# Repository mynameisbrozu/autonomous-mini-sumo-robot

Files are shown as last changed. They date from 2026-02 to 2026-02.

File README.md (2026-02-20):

## Autonomous mini sumo robot based on black pill STM32f411 microcontroller
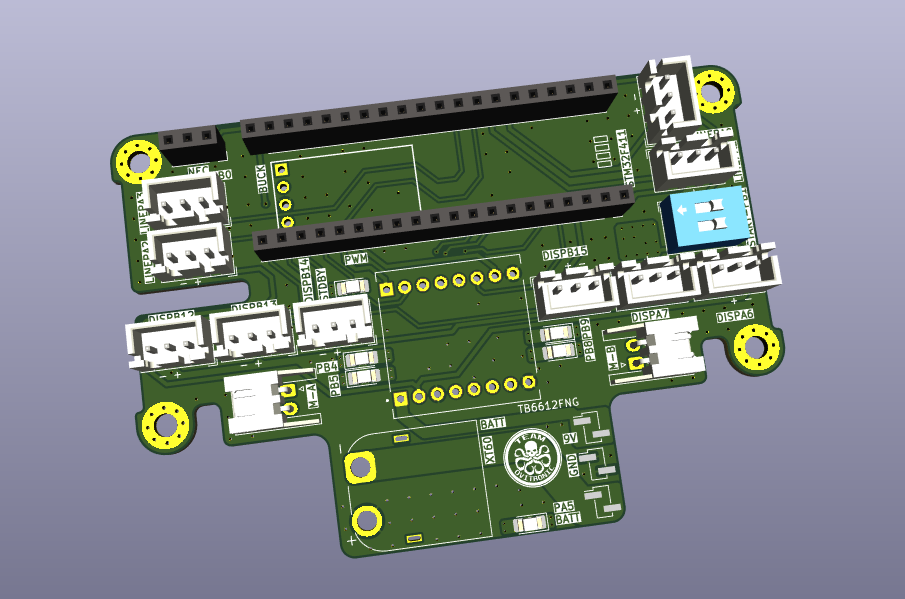
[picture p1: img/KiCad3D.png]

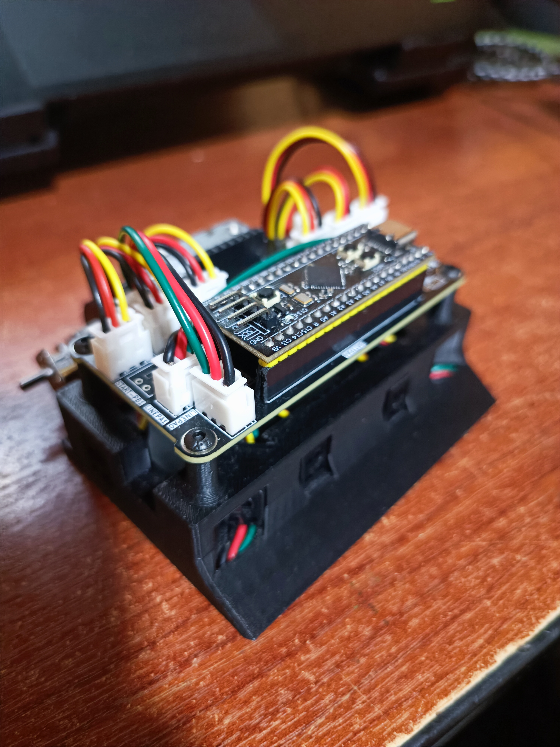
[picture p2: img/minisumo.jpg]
 
## PCB in KiCad 
| Schematic | Routing |
|---|---|
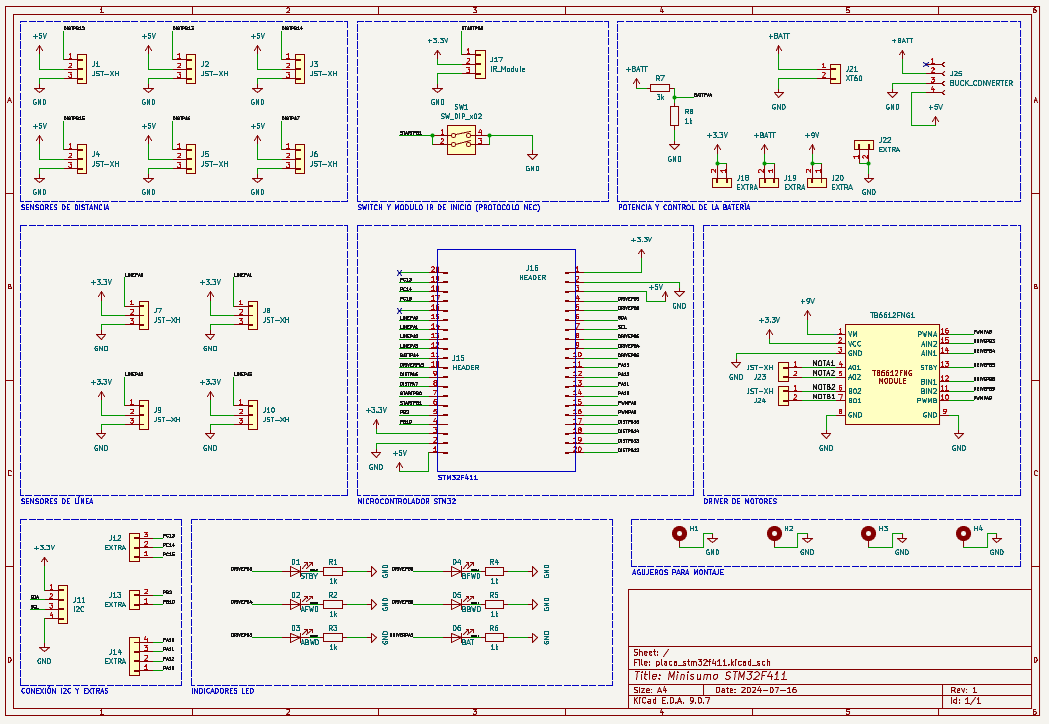
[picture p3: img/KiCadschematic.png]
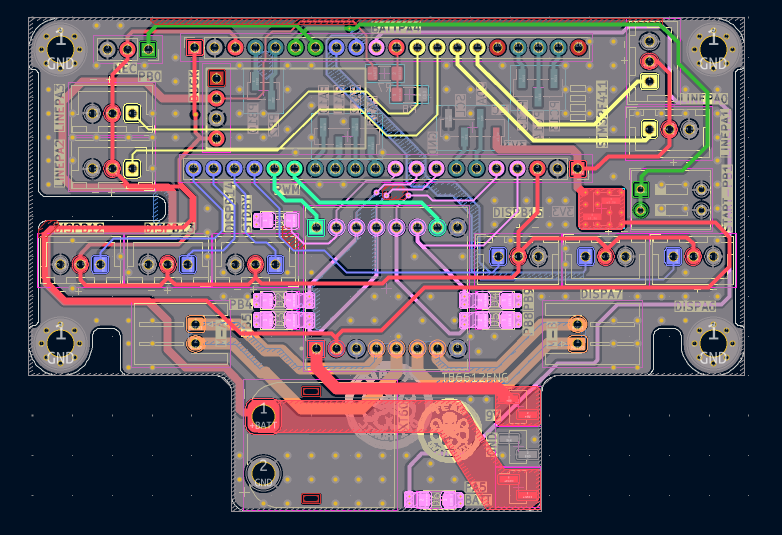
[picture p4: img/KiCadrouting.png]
|  |  |
## Pin selection - STM32F411
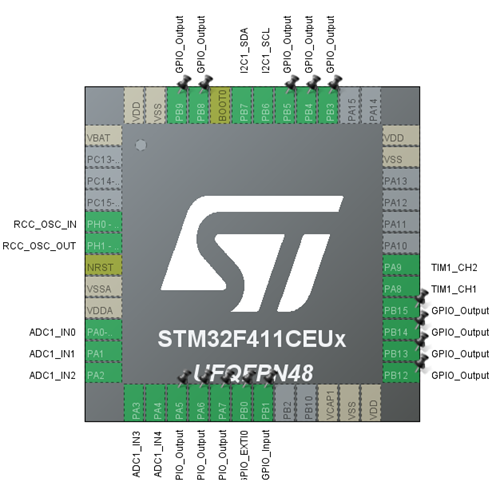
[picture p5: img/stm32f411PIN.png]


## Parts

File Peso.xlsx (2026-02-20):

 | Cantidad | Peso (gr) | TOTAL (gr)
Tornillos | 8 | 1.4 | 11.2
STM32 | 1 | 7.1 | 7.1
Placa | 1 | 32.1 | 32.1
Sensor de distancia | 6 | 3.1 | 18.6
Sensor de linea | 2 | 0.9 | 1.8
Batería | 1 | 97.7 | 97.7
Módulo IR | 1 | 2.1 | 2.1
Motores | 2 | 22 | 44
Ruedas | 2 | 23 | 46
TOTAL |  |  | 260.6 | gramos
Partes impresas | 239.4 |  |  | gramos

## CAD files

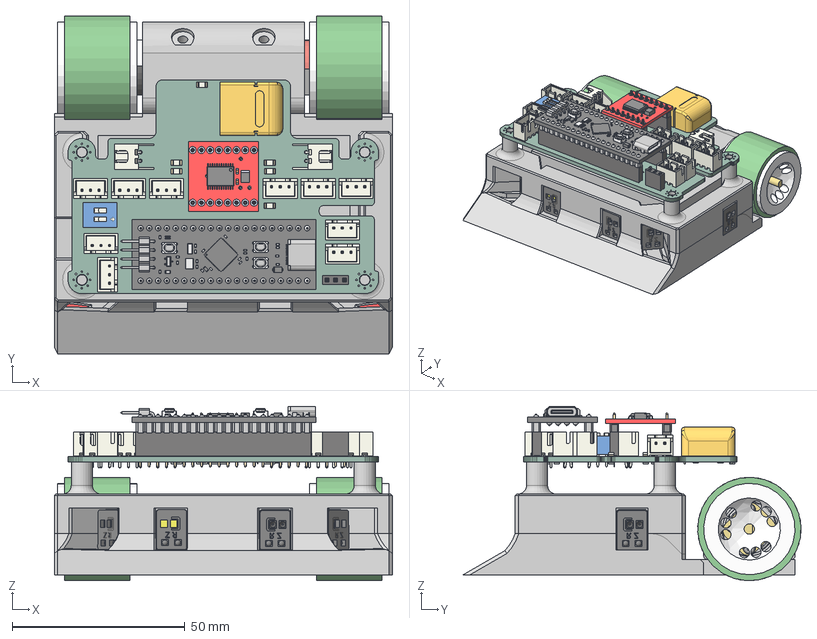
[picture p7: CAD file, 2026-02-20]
CAD/SumoPromedio.step
98.1 x 98.0 x 50.5 mm
16mm Dc Motor x 2
Wheel sumoZade x 2
rubber sumozade x 2
Chasis
qtr-1a-reflectance-sensor
qtr-1a-reflectance-sensor v1(Mirror)
RZ60S - Base x 3
RZ60S - Plastico Amarelo x 6
RZ60S - Base(Mirror)
RZ60S - Base(Mirror) (1)
RZ60S - Base(Mirror) (2)
BATERIA2S
LED_1206_3216Metric_6 x 6
JST_B3B_XH_A x 10
JST_S2B_XH_A_1 x 2
ROB-14450_1
PinSocket_1x08_P254mm_Vertical x 2
PinSocket_1x20_P254mm_Vertical x 2
XT60PW-M_1
SW_DIP_SPSTx02_Slide_978x726mm_W762mm_P254mm
PinSocket_1x03_P254mm_Vertical
R_1206_3216Metric_8 x 8
_autosave-placa_stm32f411 PCB
Board_001
STM32F4 Chip_001
Surface Mount Transistor_001
0603 Resistor_001
0603 Capacitor_001
0402 Capacitor_001
0402 Resistor_001
0402 Resistor_002
0402 Resistor_003
0402 Resistor_004
0402 Resistor_005
0402 Resistor_006
0402 Resistor_007
0402 Resistor_008
0402 Capacitor_002
0402 Capacitor_003
0402 Capacitor_004
0402 Capacitor_005
0402 Capacitor_006
0402 Capacitor_007
0402 Capacitor_008
0402 Capacitor_009
0402 Capacitor_010
0402 Capacitor_011
0402 Capacitor_012
0402 Capacitor_013
Diode 2_001
SM LED_001
1x20 Male Header_001
1x20 Male Header_002
Tac Switch_001
Tac Switch_002
Tac Switch_003
USB-C Connector_001
1x4 Right Angle Male Header_001
Crystal 1_001
Crystal 2_001

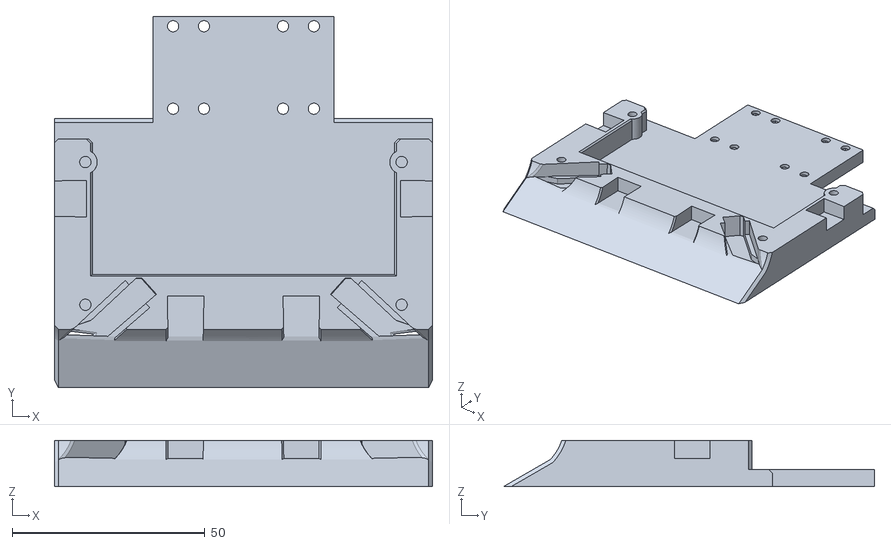
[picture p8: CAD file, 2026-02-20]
Chasis/STLs/Base principal.stl
98.0 x 96.2 x 12.0

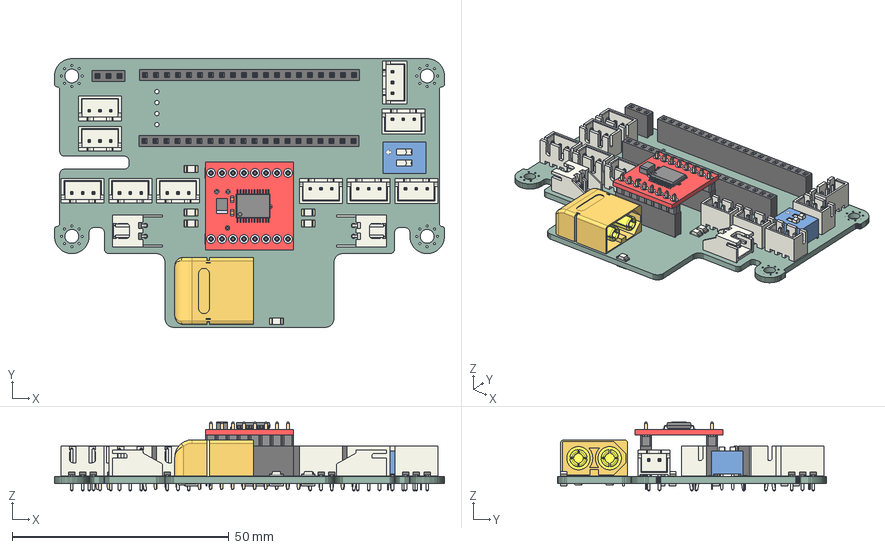
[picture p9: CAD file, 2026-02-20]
placa_stm32f411/placa_stm32f411.step
90.0 x 62.0 x 15.9 mm
LED_1206_3216Metric x 6
JST_B3B_XH_A x 10
JST_S2B_XH_A_1 x 2
ROB-14450
PinSocket_1x08_P254mm_Vertical x 2
PinSocket_1x20_P254mm_Vertical x 2
XT60PW-M
SW_DIP_SPSTx02_Slide_978x726mm_W762mm_P254mm
PinSocket_1x03_P254mm_Vertical
R_1206_3216Metric x 8
_autosave-placa_stm32f411 PCB

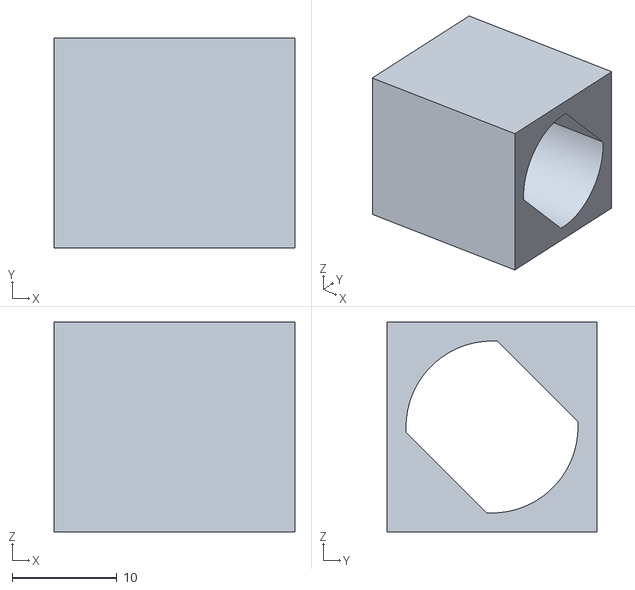
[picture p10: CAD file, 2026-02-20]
Pruebas_tolerancias/pruebaLONG_enganche_motor_t0p2.stl
23.0 x 20.0 x 20.0

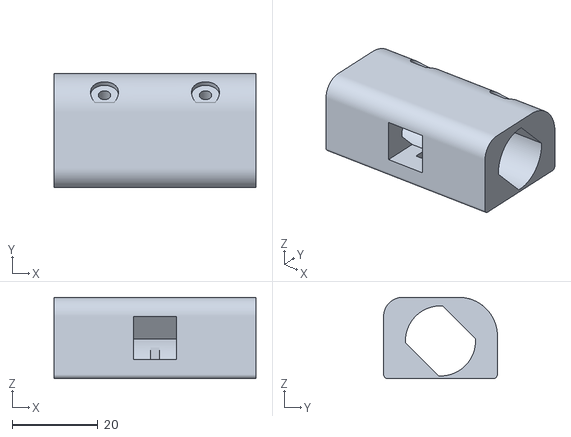
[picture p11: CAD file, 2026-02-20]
Chasis/Enganche de motores_rev1.stl
47.0 x 26.5 x 18.9

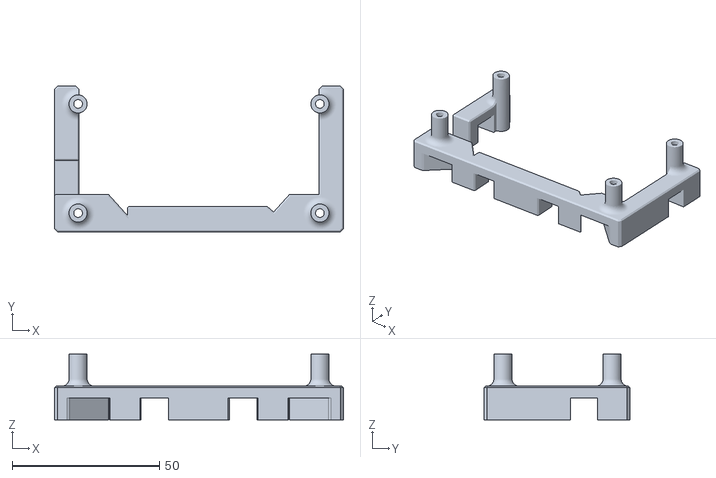
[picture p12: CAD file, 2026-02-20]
Chasis/STLs/Cubierta superior.stl
98.0 x 49.4 x 22.3

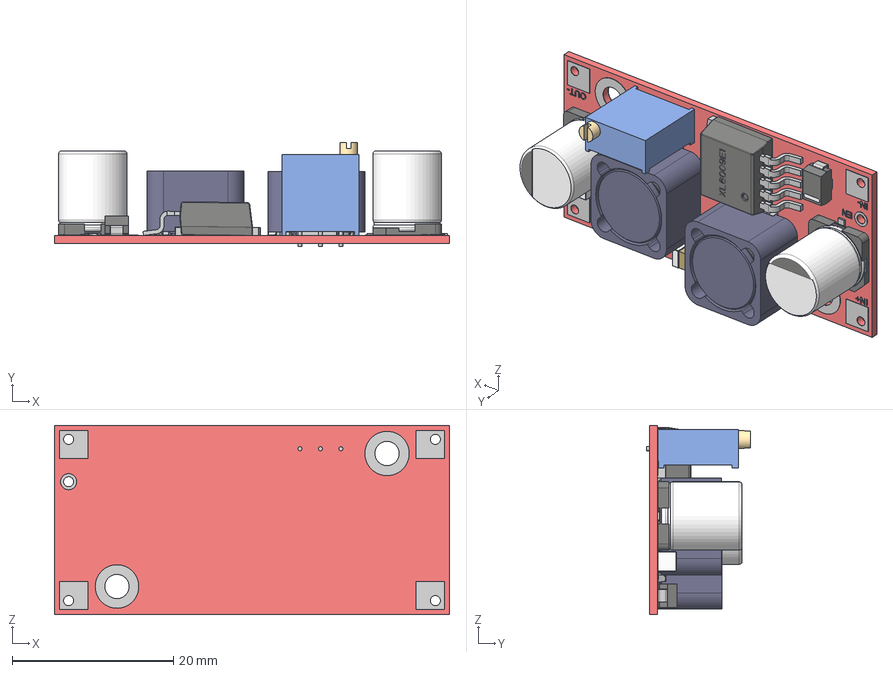
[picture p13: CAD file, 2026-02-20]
placa_stm32f411/xl6009_DCDC_BoostBuck.step
49.0 x 13.0 x 23.5 mm
KERN_ x 2
KERN___1_ x 2
KERN___2_ x 2
SCHALE_ x 2
PIN_ x 2
PIN___1_ x 2
3296W_V3
CAPACITOR1 x 2
Pads
Screen

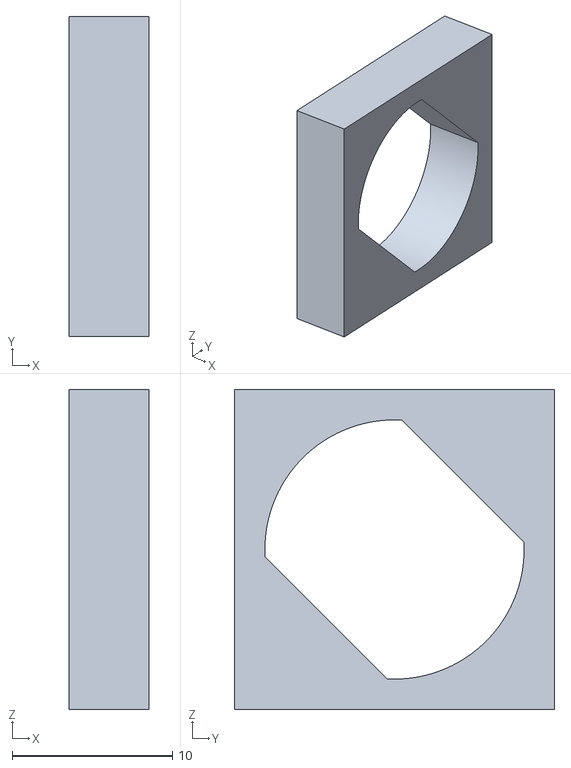
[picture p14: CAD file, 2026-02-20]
Pruebas_tolerancias/prueba_enganche_motor_t0p1.stl
5.00 x 20.0 x 20.0

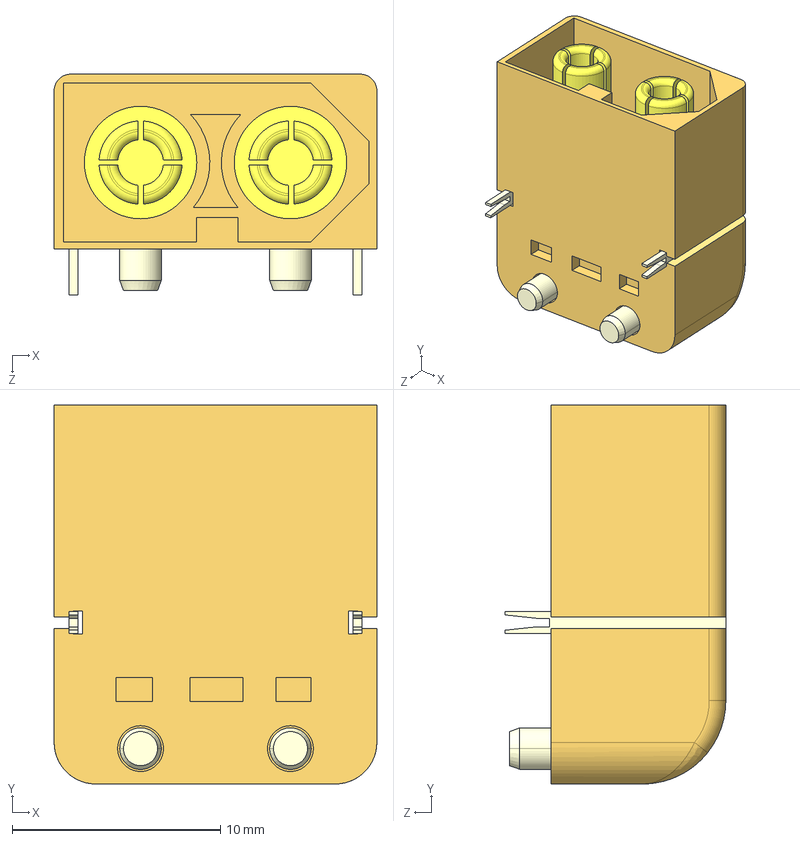
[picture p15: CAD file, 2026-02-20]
placa_stm32f411/XT60PW-M.STEP
15.5 x 18.2 x 10.6 mm

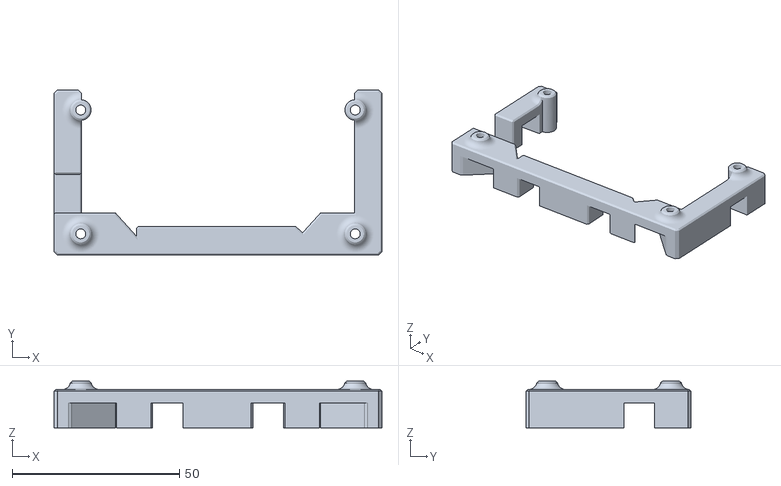
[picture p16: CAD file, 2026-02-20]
Chasis/Cubierta superior_rev2.stl
98.0 x 49.4 x 13.9

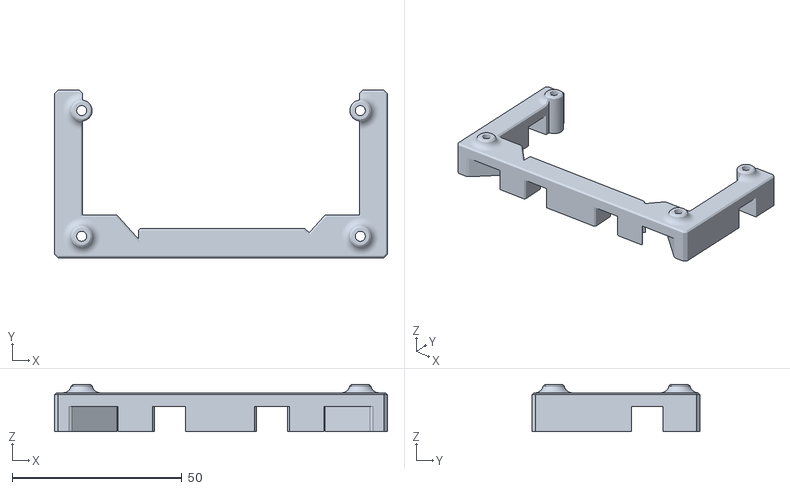
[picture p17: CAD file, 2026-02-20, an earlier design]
Chasis/Cubierta superior_rev1.stl
98.0 x 49.4 x 13.9

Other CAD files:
Chasis/Base principal_rev2.stl
Chasis/STLs/Enganche de motores.stl
Pruebas_tolerancias/prueba_enganche_motor_t0p3.stl
Pruebas_tolerancias/pruebaLONG_enganche_motor_t0p15.stl
Pruebas_tolerancias/prueba_enganche_motor_t0p2.stl
Pruebas_tolerancias/prueba_enganche_motor.stl
Chasis/Base principal_rev1.stl
placa_stm32f411/xl6009_DCDC_BoostBuck.f3d

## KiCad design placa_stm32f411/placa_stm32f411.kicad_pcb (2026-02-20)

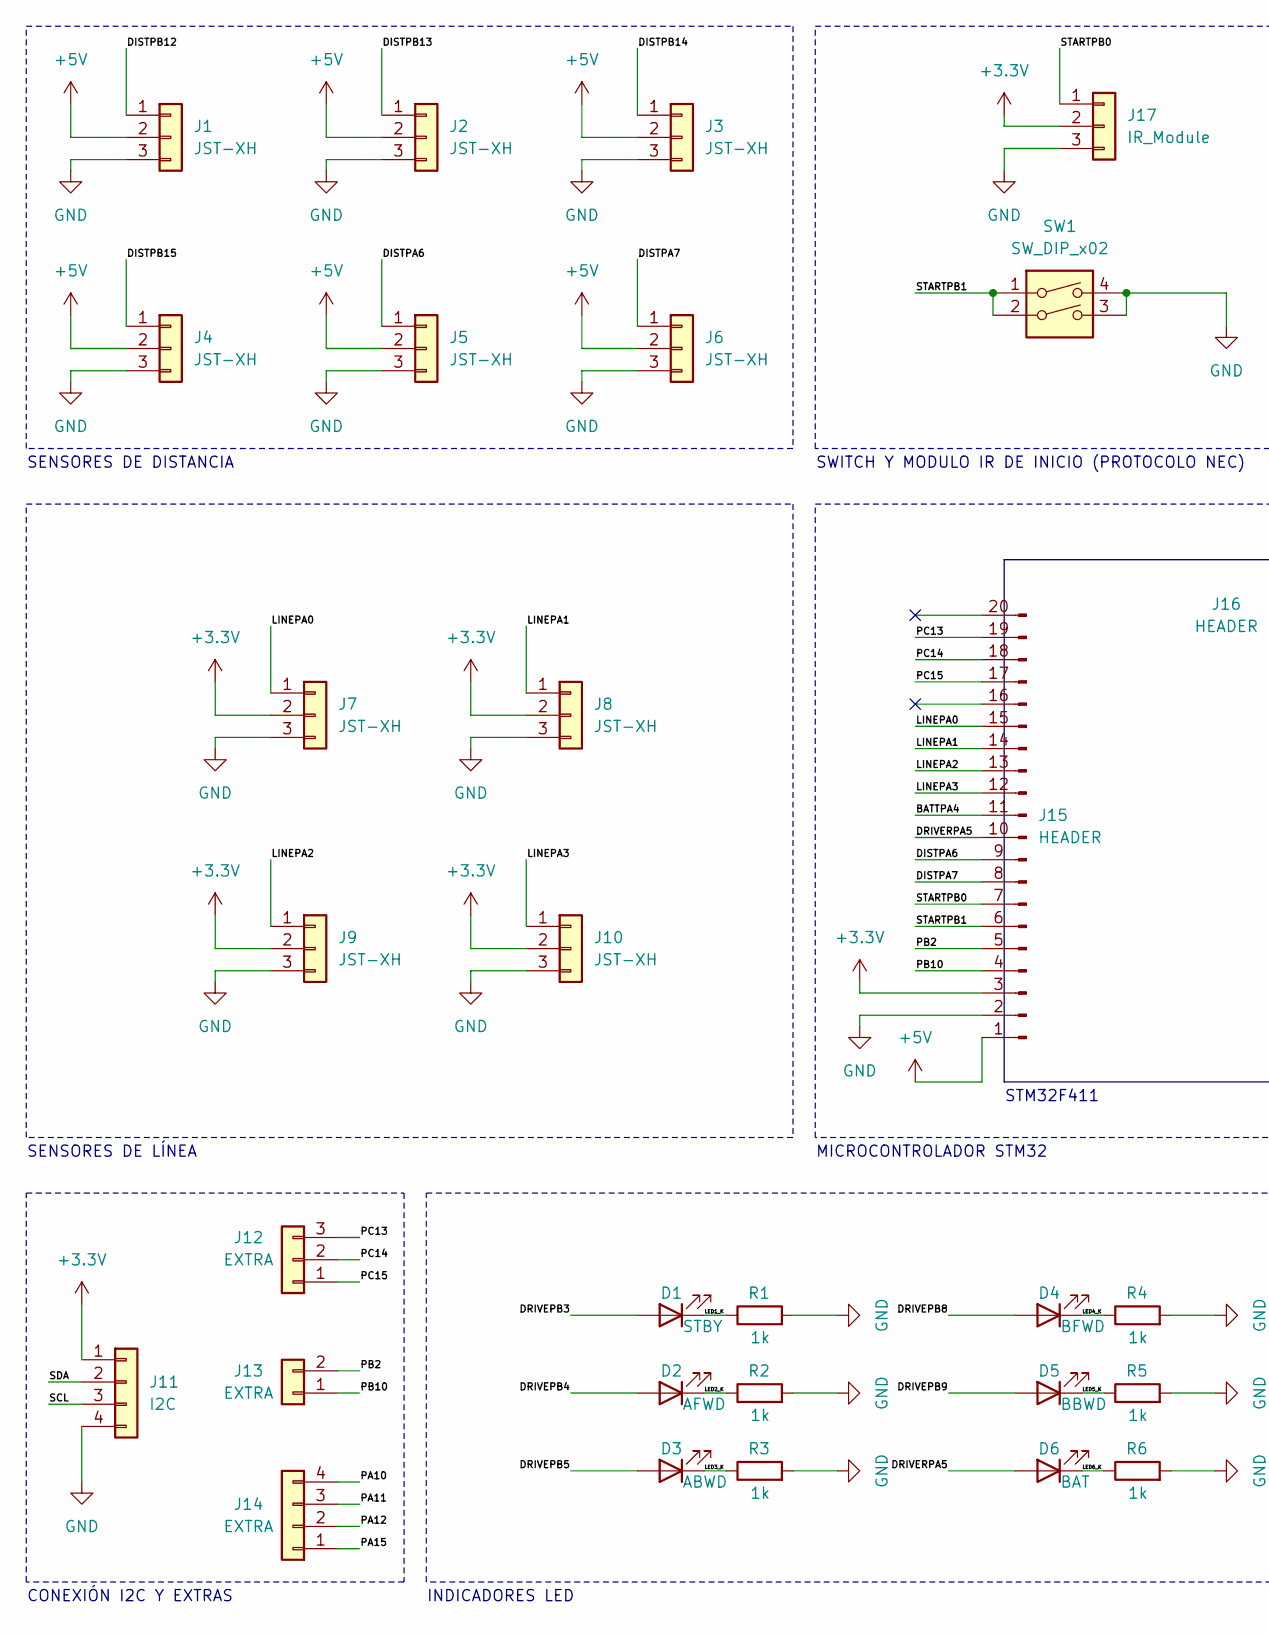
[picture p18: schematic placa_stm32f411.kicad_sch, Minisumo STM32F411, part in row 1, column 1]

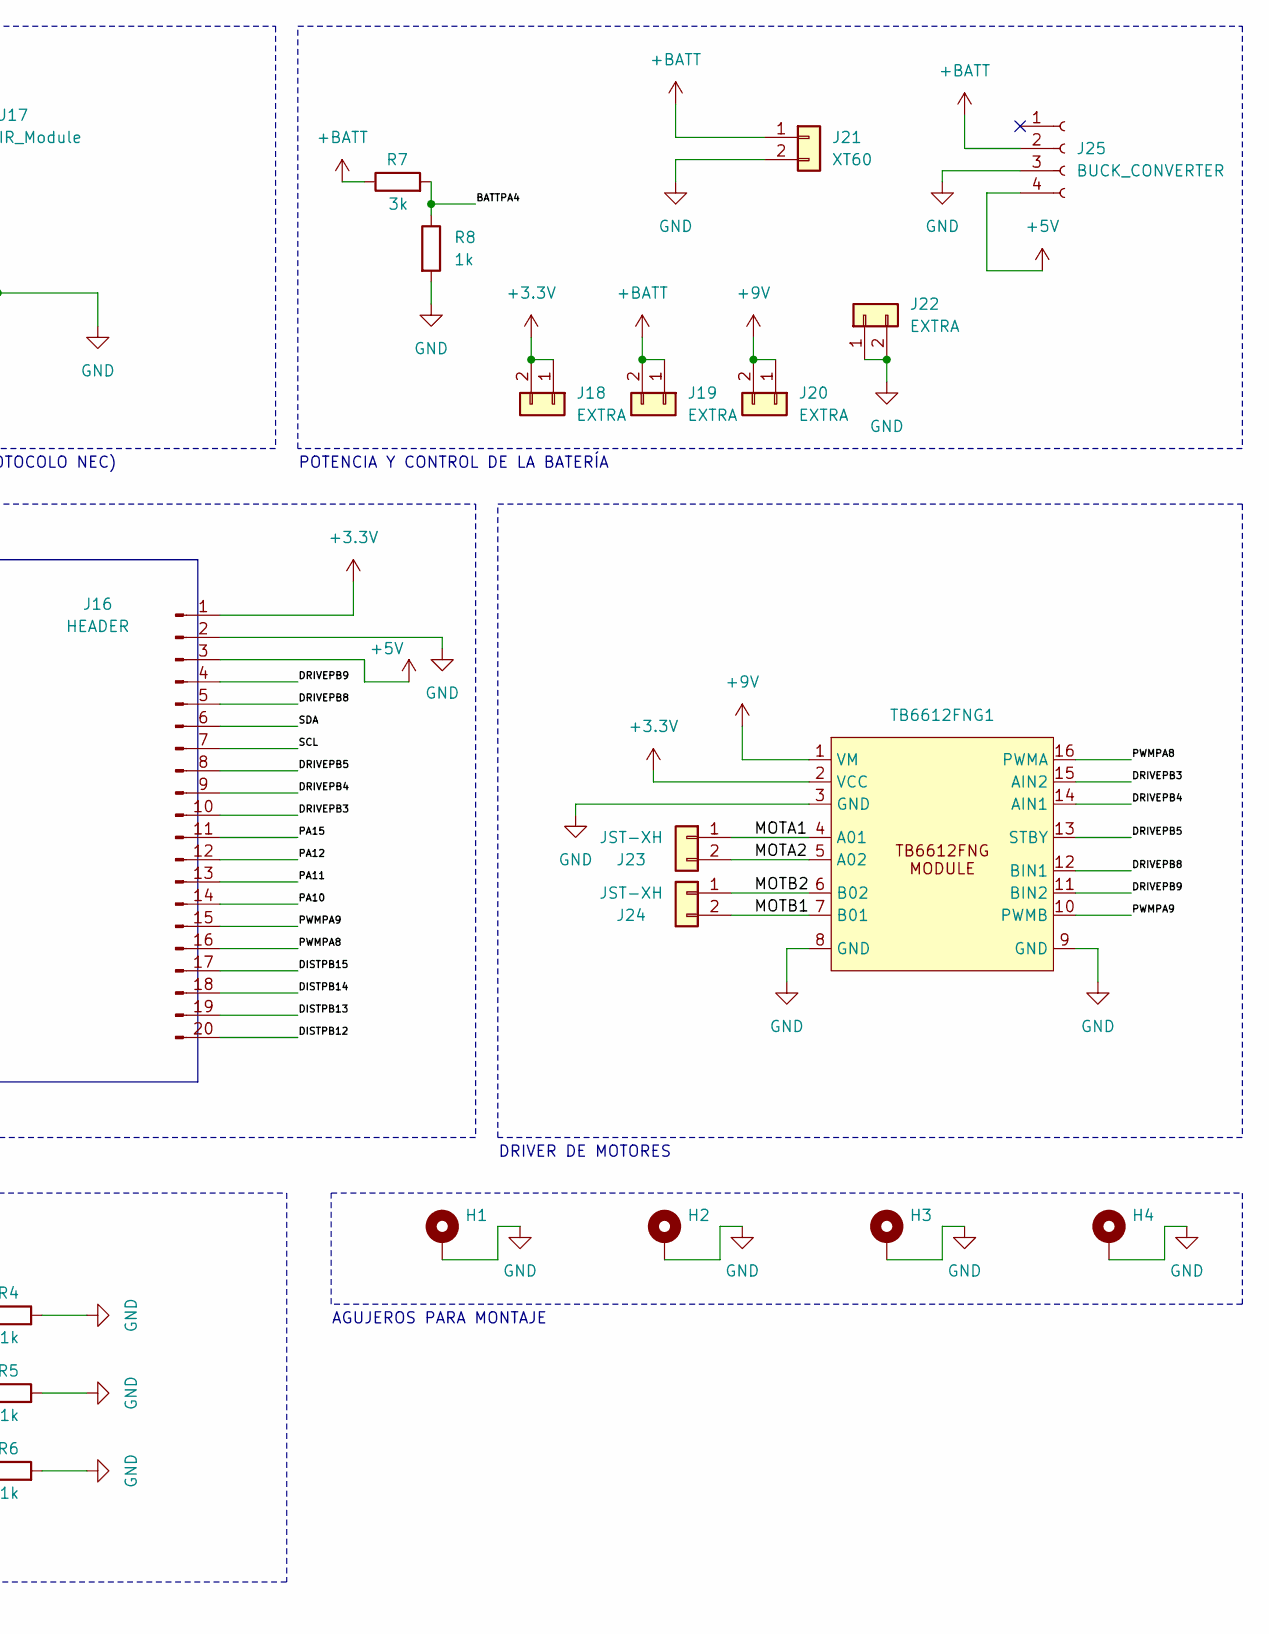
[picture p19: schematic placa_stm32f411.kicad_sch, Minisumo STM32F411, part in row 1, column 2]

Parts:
D1: STBY; LED_1206_3216Metric_Pad1.42x1.75mm_HandSolder
D2: AFWD; LED_1206_3216Metric_Pad1.42x1.75mm_HandSolder
D3: ABWD; LED_1206_3216Metric_Pad1.42x1.75mm_HandSolder
D4: BFWD; LED_1206_3216Metric_Pad1.42x1.75mm_HandSolder
D5: BBWD; LED_1206_3216Metric_Pad1.42x1.75mm_HandSolder
D6: BAT; LED_1206_3216Metric_Pad1.42x1.75mm_HandSolder
H1, H2, H3, H4: MountingHole_Pad; MountingHole_3.2mm_M3_Pad_Via
J1, J2, J3, J4, J5, J6, J7, J8, J9, J10: JST-XH; JST_XH_B3B-XH-A_1x03_P2.50mm_Vertical
J11: I2C; PinHeader_1x04_P2.00mm_Vertical_SMD_Pin1Left
J12: EXTRA; PinHeader_1x03_P2.00mm_Vertical_SMD_Pin1Left
J13, J18, J19, J20, J22: EXTRA; PinHeader_1x02_P2.00mm_Vertical_SMD_Pin1Left
J14: EXTRA; PinHeader_1x04_P2.00mm_Vertical_SMD_Pin1Left
J15, J16: HEADER; PinSocket_1x20_P2.54mm_Vertical
J17: IR_Module; PinSocket_1x03_P2.54mm_Vertical
J21: XT60; AMASS_XT60PW-M_1x02_P7.20mm_Horizontal
J23, J24: JST-XH; JST_XH_S2B-XH-A-1_1x02_P2.50mm_Horizontal
J25: BUCK_CONVERTER; PinSocket_1x04_P2.54mm_Vertical
R1, R2, R3, R4, R5, R6, R8: 1k; R_1206_3216Metric_Pad1.30x1.75mm_HandSolder
R7: 3k; R_1206_3216Metric_Pad1.30x1.75mm_HandSolder
SW1: SW_DIP_x02; SW_DIP_SPSTx02_Slide_9.78x7.26mm_W7.62mm_P2.54mm
TB6612FNG1: TB6612FNG_Module

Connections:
+3.3V: J7.2, J8.2, J9.2, J10.2, J11.1, J15.3, J16.1, J17.2, J18.1, J18.2, TB6612FNG1.2 (VCC); also elsewhere on the board
+5V: J1.2, J2.2, J3.2, J4.2, J5.2, J6.2, J15.1, J16.3, J25.4
+9V: J20.1, J20.2, TB6612FNG1.1 (VM); also elsewhere on the board
+BATT: J19.1, J19.2, J21.1, J25.2, R7.1
/BATTPA4: J15.11, R7.2, R8.1
/DISTPA6: J5.1, J15.9
/DISTPA7: J6.1, J15.8
/DISTPB12: J1.1, J16.20
/DISTPB13: J2.1, J16.19
/DISTPB14: J3.1, J16.18
/DISTPB15: J4.1, J16.17
/DRIVEPB3: D1.2 (A), J16.10, TB6612FNG1.15 (AIN2); also elsewhere on the board
/DRIVEPB4: D2.2 (A), J16.9, TB6612FNG1.14 (AIN1); also elsewhere on the board
/DRIVEPB5: D3.2 (A), J16.8, TB6612FNG1.13 (STBY); also elsewhere on the board
/DRIVEPB8: D4.2 (A), J16.5, TB6612FNG1.12 (BIN1); also elsewhere on the board
/DRIVEPB9: D5.2 (A), J16.4, TB6612FNG1.11 (BIN2); also elsewhere on the board
/DRIVERPA5: D6.2 (A), J15.10
/LED1_K: D1.1 (K), R1.1
/LED2_K: D2.1 (K), R2.1
/LED3_K: D3.1 (K), R3.1
/LED4_K: D4.1 (K), R4.1
/LED5_K: D5.1 (K), R5.1
/LED6_K: D6.1 (K), R6.1
/LINEPA0: J7.1, J15.15
/LINEPA1: J8.1, J15.14
/LINEPA2: J9.1, J15.13
/LINEPA3: J10.1, J15.12
/MOTA1: J23.1, TB6612FNG1.4 (A01); also elsewhere on the board
/MOTA2: J23.2, TB6612FNG1.5 (A02); also elsewhere on the board
/MOTB1: J24.2, TB6612FNG1.7 (B01); also elsewhere on the board
/MOTB2: J24.1, TB6612FNG1.6 (B02); also elsewhere on the board
/PA10: J14.4, J16.14
/PA11: J14.3, J16.13
/PA12: J14.2, J16.12
/PA15: J14.1, J16.11
/PB2: J13.2, J15.5
/PB10: J13.1, J15.4
/PC13: J12.3, J15.19
/PC14: J12.2, J15.18
/PC15: J12.1, J15.17
/PWMPA8: J16.16, TB6612FNG1.16 (PWMA); also elsewhere on the board
/PWMPA9: J16.15, TB6612FNG1.10 (PWMB); also elsewhere on the board
/SCL: J11.3, J16.7
/SDA: J11.2, J16.6
/STARTPB0: J15.7, J17.1
/STARTPB1: J15.6, SW1.1, SW1.2
GND: H1.1, H2.1, H3.1, H4.1, J1.3, J2.3, J3.3, J4.3, J5.3, J6.3, J7.3, J8.3, J9.3, J10.3, J11.4, J15.2, J16.2, J17.3, J21.2, J22.1, J22.2, J25.3, R1.2, R2.2, R3.2, R4.2, R5.2, R6.2, R8.2, SW1.3, SW1.4, TB6612FNG1.3 (GND), TB6612FNG1.8 (GND), TB6612FNG1.9 (GND); also elsewhere on the board

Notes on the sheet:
AGUJEROS PARA MONTAJE
MICROCONTROLADOR STM32
DRIVER DE MOTORES
SENSORES DE LÍNEA
STM32F411
CONEXIÓN I2C Y EXTRAS
SENSORES DE DISTANCIA
SWITCH Y MODULO IR DE INICIO (PROTOCOLO NEC)
INDICADORES LED
POTENCIA Y CONTROL DE LA BATERÍA

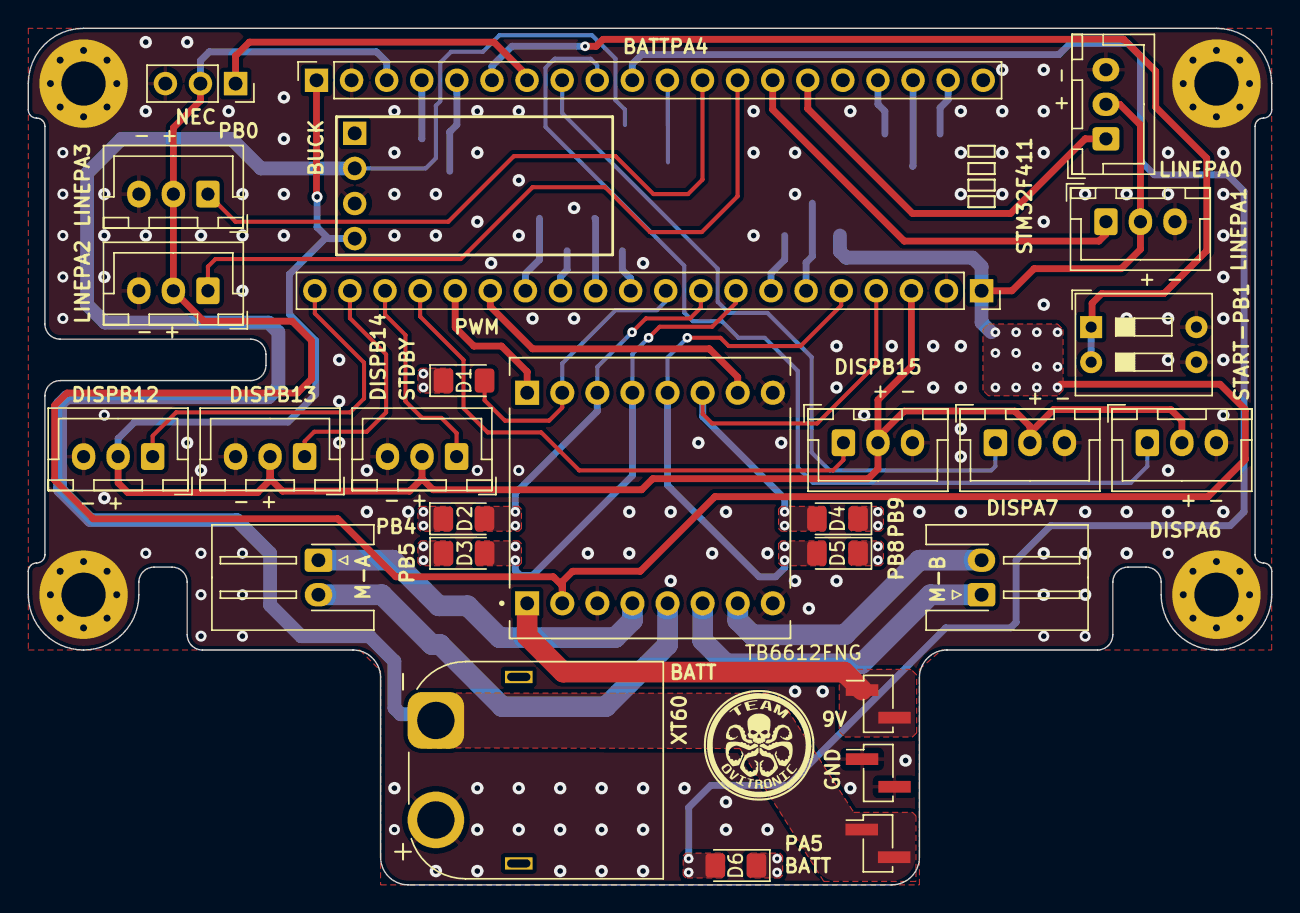
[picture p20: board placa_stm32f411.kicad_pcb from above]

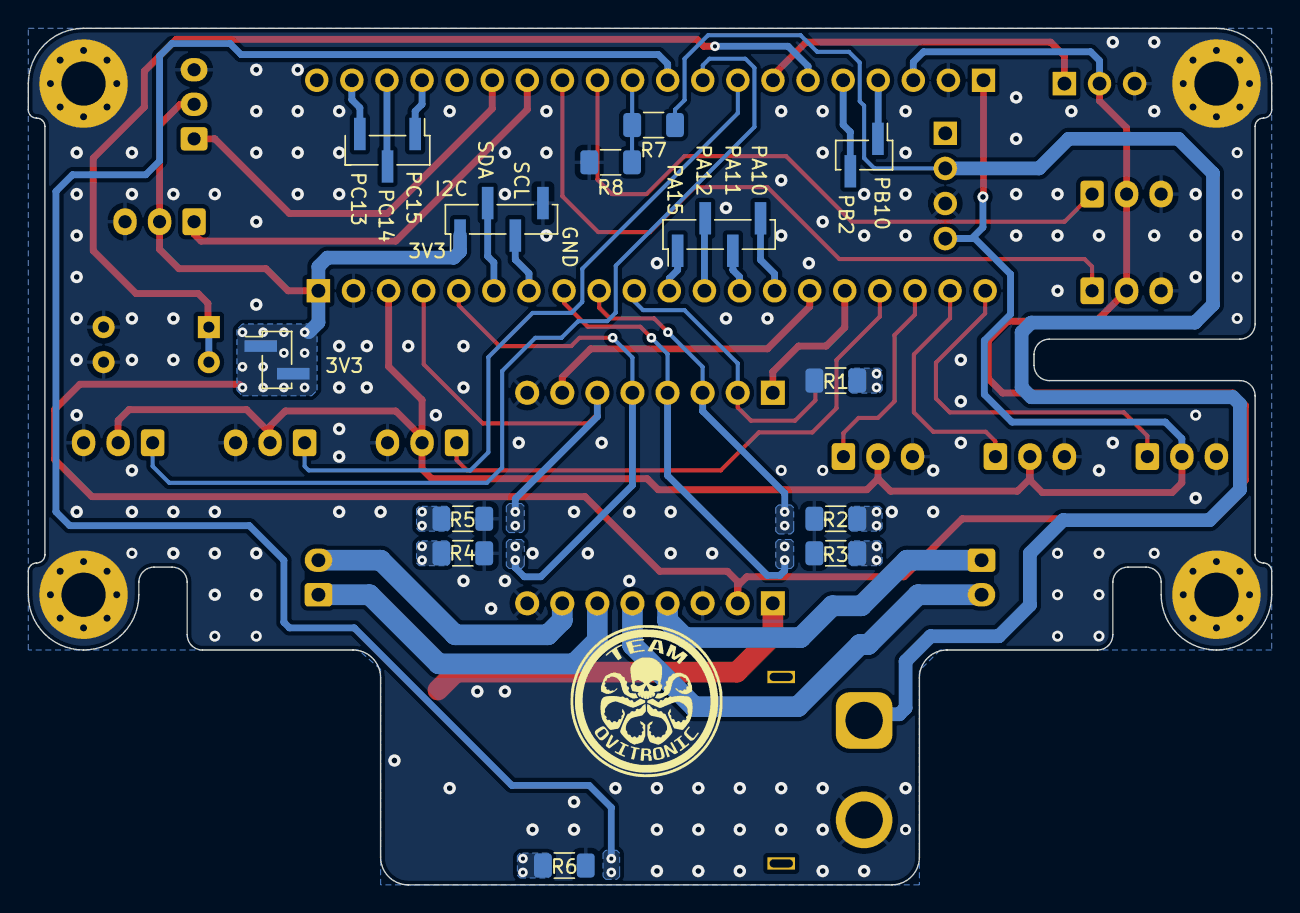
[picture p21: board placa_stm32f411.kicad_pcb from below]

Board: 2 copper layers, 90.0 x 62.0 mm, 45 parts (13 on the bottom side), 47 nets.

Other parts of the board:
TB6612FNG: TB6612FNG_Module

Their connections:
+3.3V: TB6612FNG.2 (VCC); also elsewhere on the board
+9V: TB6612FNG.1 (VM); also elsewhere on the board
/DRIVEPB3: TB6612FNG.15 (AIN2); also elsewhere on the board
/DRIVEPB4: TB6612FNG.14 (AIN1); also elsewhere on the board
/DRIVEPB5: TB6612FNG.13 (STBY); also elsewhere on the board
/DRIVEPB8: TB6612FNG.12 (BIN1); also elsewhere on the board
/DRIVEPB9: TB6612FNG.11 (BIN2); also elsewhere on the board
/MOTA1: TB6612FNG.4 (A01); also elsewhere on the board
/MOTA2: TB6612FNG.5 (A02); also elsewhere on the board
/MOTB1: TB6612FNG.7 (B01); also elsewhere on the board
/MOTB2: TB6612FNG.6 (B02); also elsewhere on the board
/PWMPA8: TB6612FNG.16 (PWMA); also elsewhere on the board
/PWMPA9: TB6612FNG.10 (PWMB); also elsewhere on the board
GND: TB6612FNG.3 (GND), TB6612FNG.8 (GND), TB6612FNG.9 (GND); also elsewhere on the board

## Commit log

2026-02-20 files upload
    [Base principal.stl, Base principal_rev1.stl, Base principal_rev2.stl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]
2026-02-20 stm32f411 pin upload
